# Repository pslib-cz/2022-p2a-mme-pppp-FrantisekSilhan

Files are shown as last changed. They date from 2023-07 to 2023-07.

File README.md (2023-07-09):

# Sorting "pointer"

 

For creating random teams, assigning people to teams, assigning people to work groups or training activities.

# What is needed?
- [strip board](https://www.aliexpress.com/item/1005001298180557.html) 25x9 holes (35 CZK / 5pcs)
- [Arduino Nano](https://www.aliexpress.com/item/1005005655120765.html) (129 CZK)
- 9V battery (~40 CZK)
- 9V baterry [clip](https://www.aliexpress.com/item/32728912830.html) (11 CZK / 10pcs)
- [mini slide switch](https://www.allelectronics.com/item/ssw-86/spdt-mini-slide-switch/1.html) (10.0 x 5.5mm body) (22 CZK)
- 2 LED strips (5 LED + 1 LED) [WS2812B](https://www.aliexpress.com/item/1005002630710155.html) (140 CZK / 1m)
- 3 TTP223 [touch buttons](https://www.aliexpress.com/item/1005004970116737.html) (15 CZK / 10pcs)
- 3pin cable + [header connectors](https://www.aliexpress.com/item/32724478308.html) (~54 female + ~33 male) (70 CZK / 20pcs)
- Final price ~451 CZK (~20,79 USD 18.06.2023)

# How to create one

## Step 0:

Print [box](./stl/box.STL) and [lid](./stl/lid.STL) on a 3D printer

## Step 1: Solder the female connectors to the strip board

As shown in the picture below, solder the female connectors to the strip board. Solder the pins marked with a colored dot to the strip board, and remove the other pins from the connector.\
Leave exactly 5 holes between the connectors in the blue rectangle, as this is where the Arduino Nano will be inserted.

<p style="display: flex; align-items: flex-start; gap: 1em;">
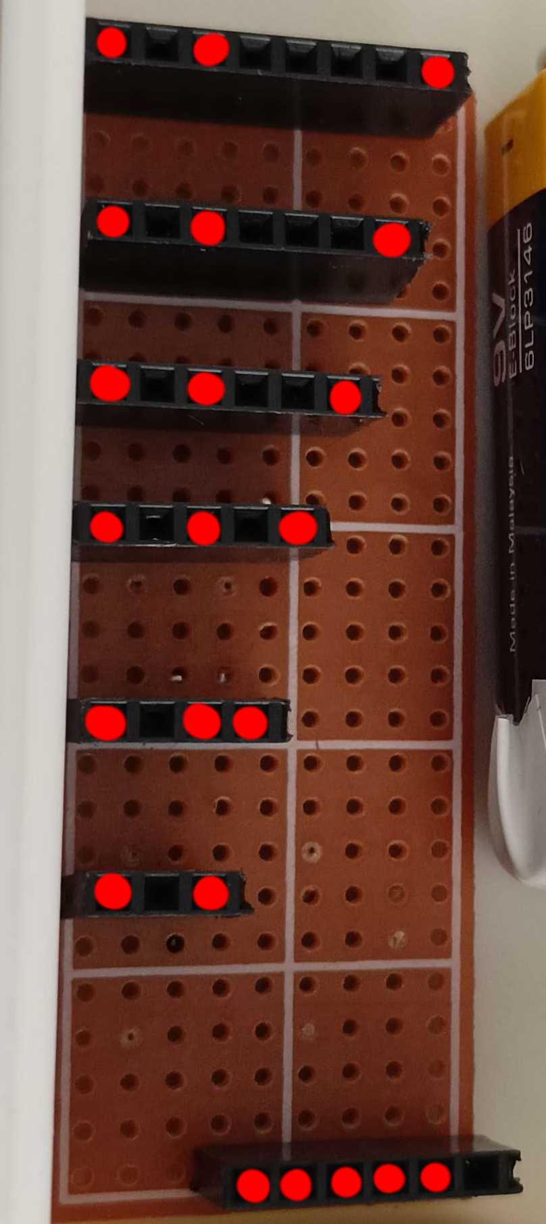
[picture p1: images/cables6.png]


</p>

## Step 2: Create male connectors for the cables

Solder a total of five male connectors to the cables, three of which are for the buttons and two for the LED strips.
Each cable will have the following pinout (based on the picture below):

- Ground pin will be on the far left.
- The two pins to the right of the ground pin will be the +5V pin.
- The data pin for each cable will be in a different location.

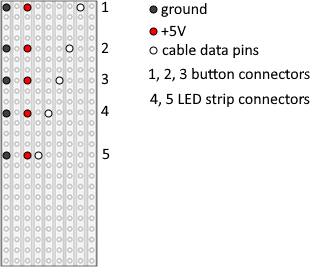
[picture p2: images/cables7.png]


For the three button cables, select the three longest connectors (labeled 1, 2 and 3 in the image above).\
For the two cables for the LED strips, select the two shortest connectors (marked 4 and 5).\
one LED strip will have 5 LEDs (marked with the number 5), the other LED strip will have only 1 LED (marked with the number 4).

## Step 2.5: Soldering the female connectors to the button cables and soldering the LED strips

Solder the female connectors to the other side of the button cables according to the pins on the buttons.

For LED strip cables, do not use female connectors, but solder the cables directly to the LED strip.

<p style="display: flex; align-items: flex-start; gap: 1em;">
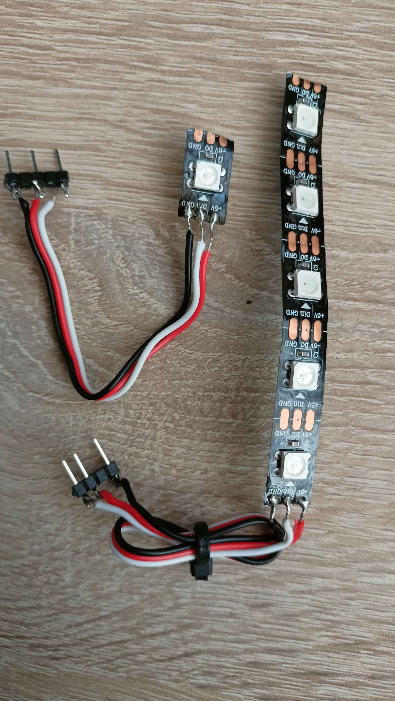
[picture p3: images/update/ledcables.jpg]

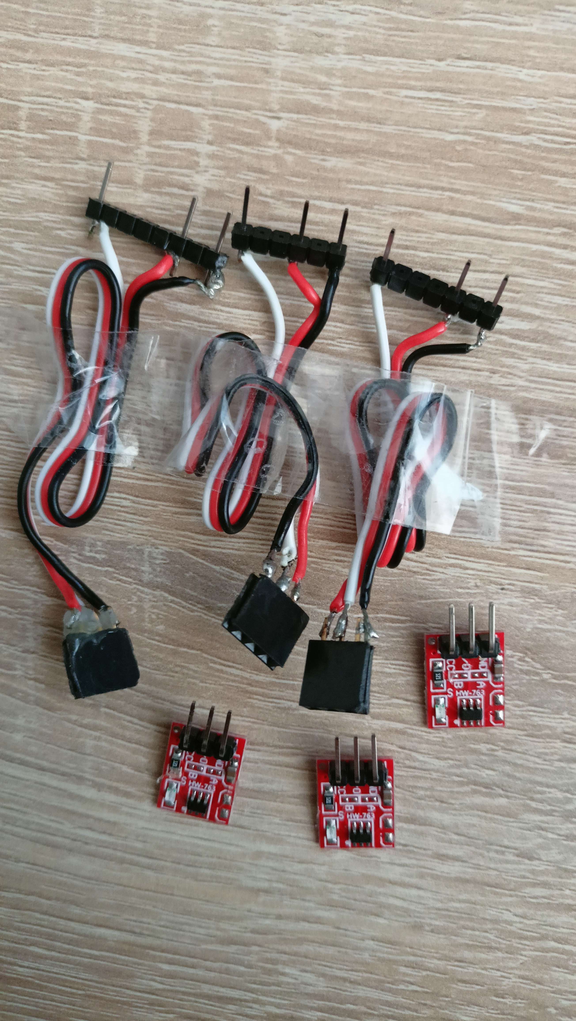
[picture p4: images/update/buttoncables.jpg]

</p>

Now you should have:
- 2 LED strip cables (one LED strip with 5 LEDs, the other LED strip with 1 LED)
- 3 cables for the buttons

## Step 3: Inserting into the box

Solder the ground from the 9V battery clip to the Arduino ground and connect the "+" of the 9V battery to the slide switch and then from the switch to the Uin of the Arduino.

Upload the provided [code](./main/main.ino) using the Arduino IDE to the Arduino and set the pins as required (according to the data pins in the image below).\
(Don't forget to include the FastLED library: Tools > Manage Libraries... (Ctrl + Shift + I) > search "FastLED" > INSTALL)

Next, insert the strip board into the box, plug the Arduino into the prepared connectors and place the battery next to it. Glue the switch into the prepared hole on the side of the box. (see image below)

Test if the Arduino turns on after you flip the switch.

<p style="display: flex; align-items: flex-start; gap: 1em;">
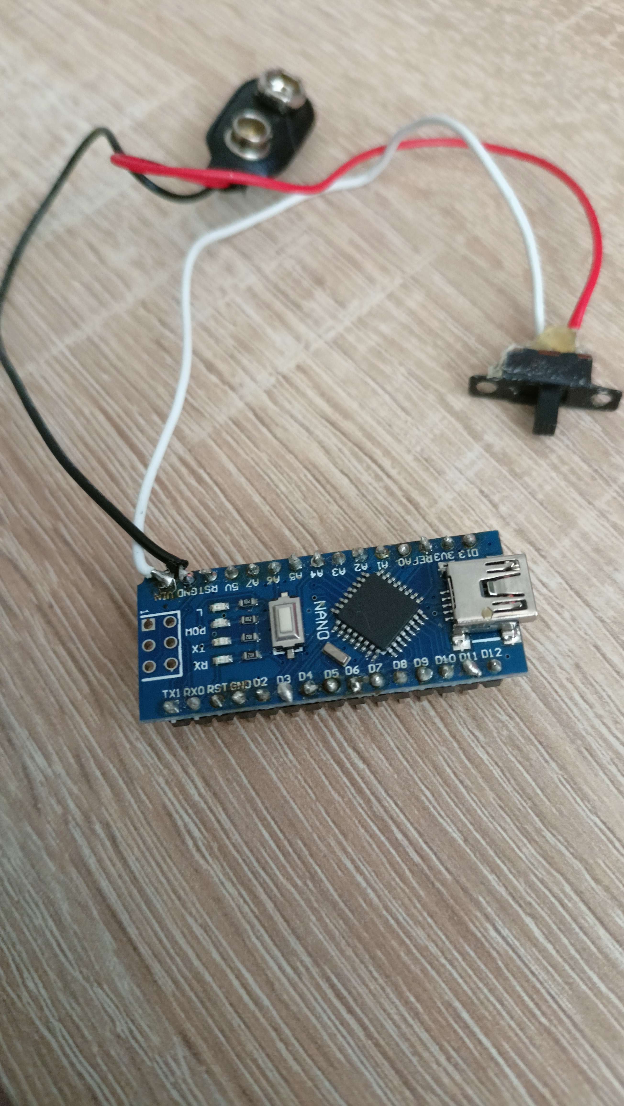
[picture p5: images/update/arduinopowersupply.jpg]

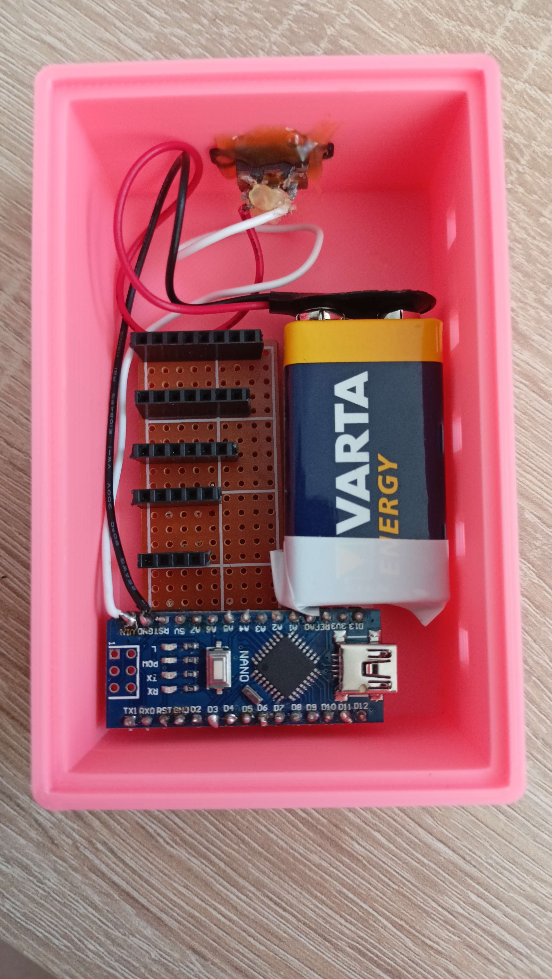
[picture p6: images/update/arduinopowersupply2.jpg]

</p>
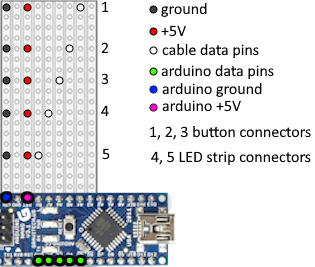
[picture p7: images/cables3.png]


## Step 4: Glue the buttons and LED strips into the lid and box

Glue all buttons and both LED strips into the prepared holes in the lid and box (see image below).

<p style="display: flex; align-items: flex-start; gap: 1em;">
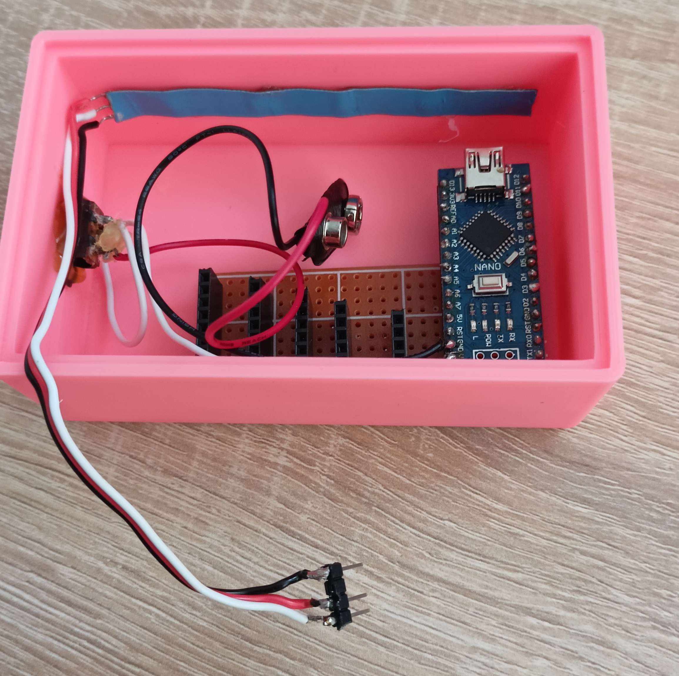
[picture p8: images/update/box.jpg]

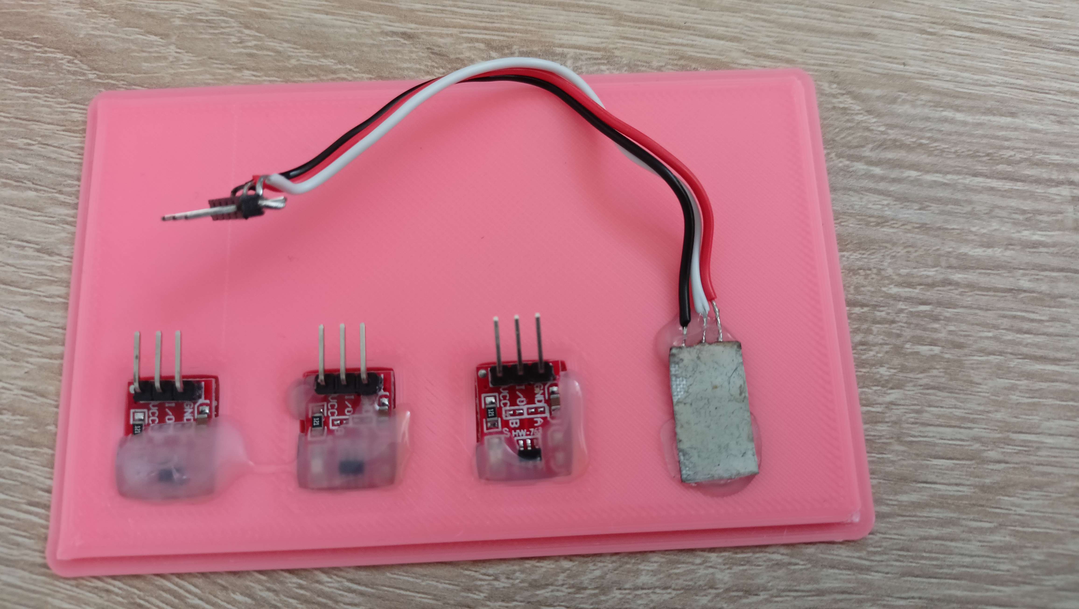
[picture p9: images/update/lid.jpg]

</p>

## Step 5: Connect all cables

Connect the prepared cables to the buttons with male connectors.\
Plug all cables into the female connectors on the strip board and close the box carefully.

Test that all buttons are working and all LEDs are showing output.

<p style="display: flex; align-items: flex-start; gap: 1em;">
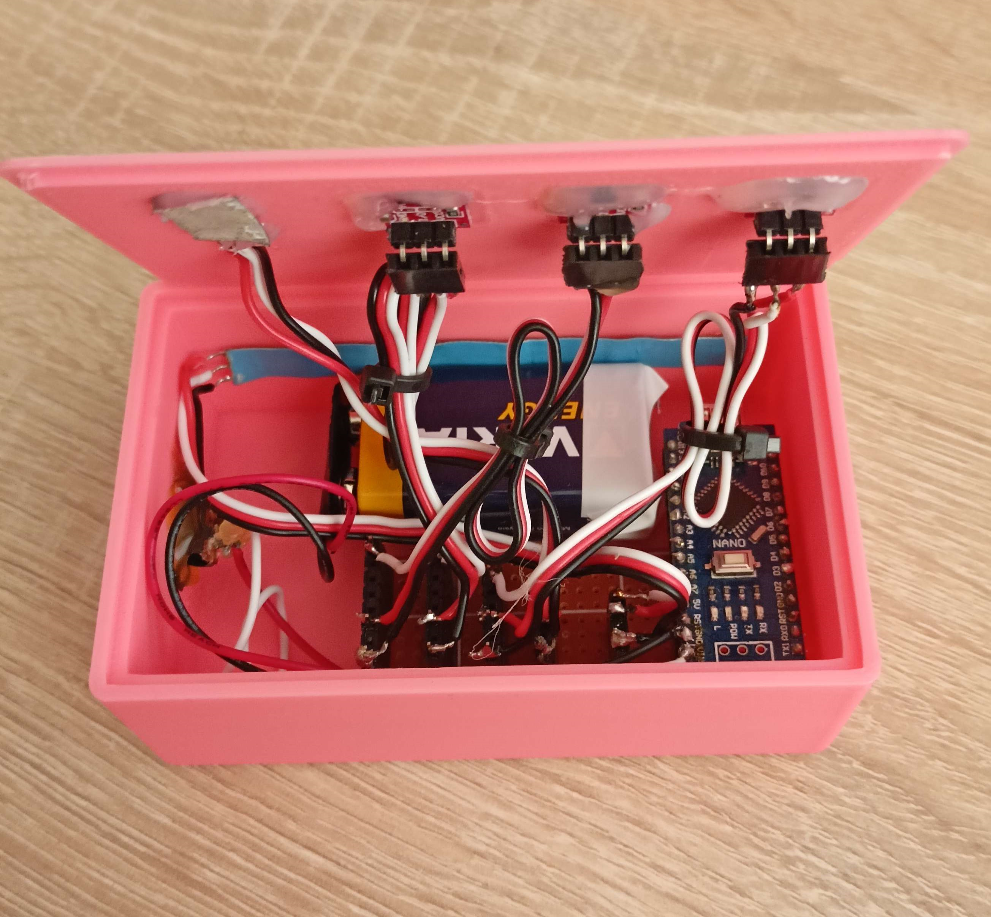
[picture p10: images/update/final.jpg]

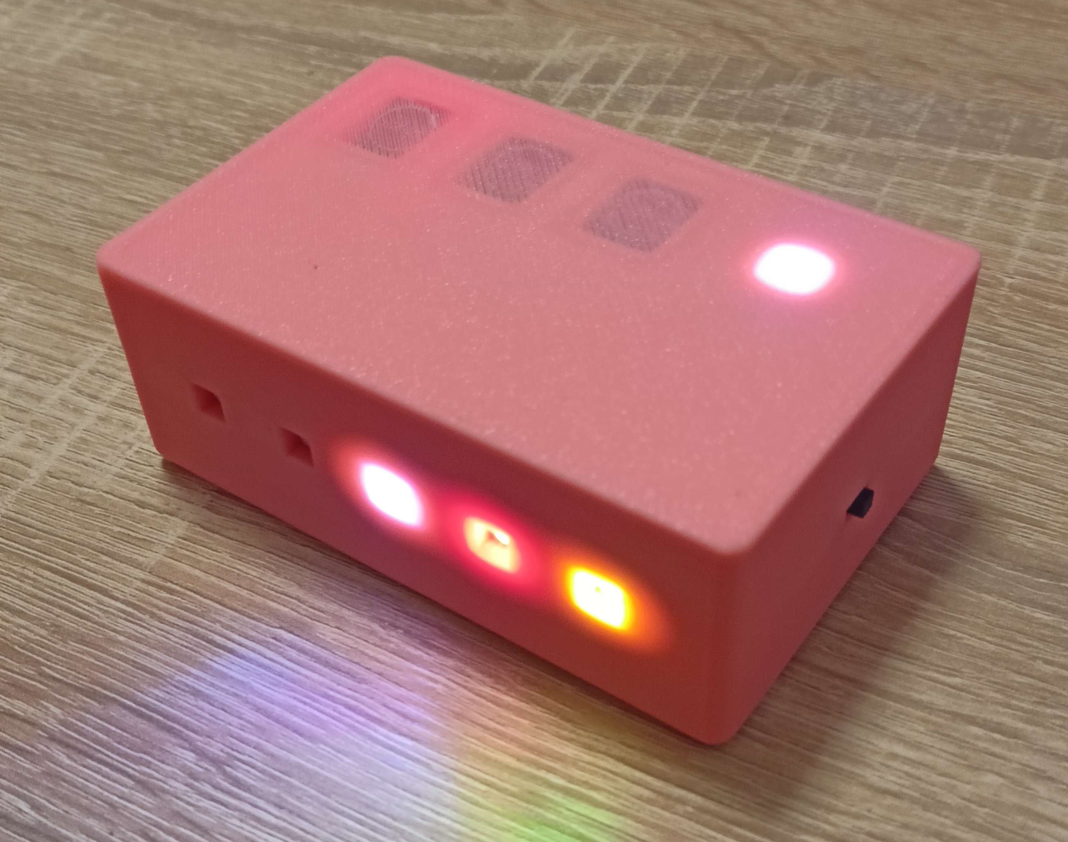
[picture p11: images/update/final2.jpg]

</p>

# Usage Instructions

The box has this basic layout (pins can be modified as needed in [code](./main/main.ino))

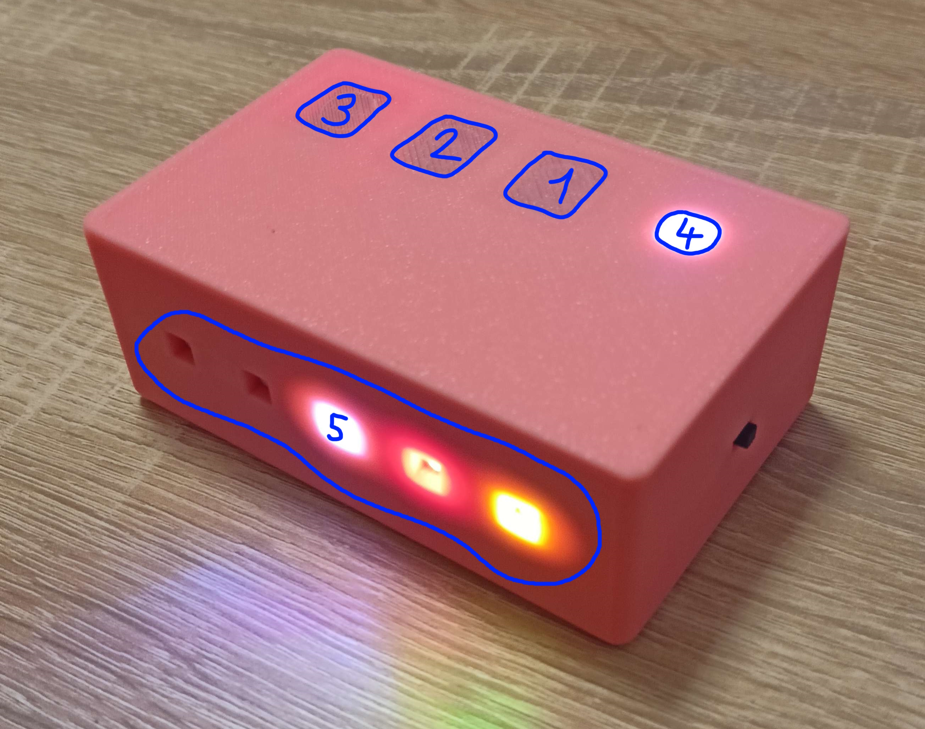
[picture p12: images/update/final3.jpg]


- 1 - Button to change the number of groups
    - When pressed, the number of selected groups will be shown on the top row of the LEDs (shown as a number 5 in the image)
    - The selection of the number of groups cycles from one group to the maximum number of groups, and then again from one group
- 2 - Button to change mode
    - Each press of the button changes the currently selected mode
    - The selected mode cycles between 3 modes (see point 4)
- 3 - Button for stepping
    - The main button that triggers one "draw" according to the selected mode
- 4 - LED showing the currently selected mode
    - The pointer has 3 modes
        - ## Green - Yes/No
            - Lights the LED strip green (YES) or red (NO)
            - Chance of YES is 50% and for each NO the chance of YES increases by 10%
            - If YES is displayed, the chance is set back to 50%
        - ## Red - Shift cycling group
            - Groups are progressively displayed by cycling the LED to the side
            - The LEDs on the output are each a different color, each color represents a different group
            - 
        - ## Blue - Random group cycling
            - Works the same as the red mode, but the LED cycling is not to the side, but a random group is always selected. The final number of people in a group is even
            - 
- 5 - LEDs showing an output
    - Each time the step button is pressed, the output here is displayed according to the selected mode and number of groups
    - Each time the button to change the number of groups is pressed, the currently selected number of groups is displayed here

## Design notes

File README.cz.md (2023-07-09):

# Rozřazovací "ukazovátko"

 

Pro tvorbu náhodných týmů, rozřazení lidí do týmů, rozřazování do pracovních skupin nebo vzdělávacích aktivit.

# Co je potřeba?
- [strip board](https://www.aliexpress.com/item/1005001298180557.html) 25x9 děr (35 CZK / 10ks)
- [Arduino Nano](https://www.aliexpress.com/item/1005005655120765.html) (129 CZK)
- 9V baterie (~40 CZK)
- [Klip](https://www.aliexpress.com/item/32728912830.html) na 9V baterii (11 CZK / 10ks)
- [mini posuvný přepínač](https://www.allelectronics.com/item/ssw-86/spdt-mini-slide-switch/1.html) (10.0 x 5.5mm tělo) (22 CZK)
- 2 LED pásky (5 LED + 1 LED) [WS2812B](https://www.aliexpress.com/item/1005002630710155.html) (140 CZK / 1m)
- 3 TTP223 [dotyková tlačítka](https://www.aliexpress.com/item/1005004970116737.html) (15 CZK / 10ks)
- 3pinový kabel + [header konektory](https://www.aliexpress.com/item/32724478308.html) (~54 samičích + ~33 samčích) (70 CZK / 20ks)
- Finální cena ~451 CZK (18.06.2023)

# Výroba

## Krok 0:

Vytiskněte [krabičku](./stl/box.STL) a [víko](./stl/lid.STL) na 3D tiskárně

## Krok 1: Připájení samičích (female) konektorů na strip board

Podle obrázku níže připájejte samičí konektory na strip board. Piny označené barevnou tečkou připájejte ke strip boardu, zatímco ostatní piny vyjměte z konektoru.\
Mezeru mezi konektory v modrém obdélníku zanechte přesně 5 děr, protože zde bude zasazeno Arduino Nano.

<p style="display: flex; align-items: flex-start; gap: 1em;">


</p>

## Krok 2: Vytvoření samčích (male) konektorů pro kabely

Připájejte celkem pět samčích konektorů na kabely, z toho tři kabely pro tlačítka a dva kabely pro LED pásy.
Každý kabel bude mít následující uspořádání pinů (založené na obrázku níže):

- Ground pin bude úplně vlevo.
- Dva piny vpravo od ground pinu bude +5V pin.
- Data pin pro každý kabel bude na jiném místě.



Pro tři kabely pro tlačítka vyberte tři nejdelší konektory (označené jako 1, 2 a 3 v obrázku výše).\
Pro dva kabely pro LED pásy vyberte dva nejkratší konektory (označené jako 4 a 5).\
jeden LED pás bude mít 5 LEDek (označen číslem 5), druhý LED pás bude mít pouze 1 LEDku (označen číslem 4).

## Krok 2.5: Připájení samičích konektorů na tlačítkové kabely a připojení LED pásků

Připájejte samičí konektory na druhou stranu tlačítkových kabelů podle pinů na tlačítkách.

Pokud jde o kabely pro LED pásky, nepoužívejte samičí konektory, ale připájejte kabely přímo k LED pásku.

<p style="display: flex; align-items: flex-start; gap: 1em;">


</p>

Teď byste měli mít:
- 2 kabely s LED pásy (jeden LED pás s 5 LEDkami, druhý LED pás s 1 LEDkou)
- 3 kabely pro tlačítka

## Krok 3: Zasazení do boxu

Připájejte zem z klipu pro 9V baterii na zem Arduina a "+" 9V baterie přípájejte na posuvný přepínač a následně z přepínače na Uin Arduina.

Nahrajte připravený [kód](./main/main.ino) pomocí Arduino IDE do Arduina a nastavte piny dle potřeby (podle data pinů na obrázku níže).\
(Nezapomeňte připojit knihovnu FastLED: Tools > Manage Libraries... (Ctrl + Shift + I) > vyhledejte "FastLED" > INSTALL)

Následně vložte strip board do boxu, zasuňte Arduino do připravených konektorů a vedle položte baterii. Přepínač přilepte do připravené díry na boku krabičky. (viz foto níže)

Otestujte, zda se Arduino zapne po přepnutí přepínače.

<p style="display: flex; align-items: flex-start; gap: 1em;">


</p>


## Krok 4: Vlepení tlačítek a LED pásků do víka a boxu

Vlepte všechna tlačítka a oba LED pásky do připravených děr ve víku a krabičce. (viz foto níže)

<p style="display: flex; align-items: flex-start; gap: 1em;">


</p>

## Krok 5: Zapojení všech kabelů

Ke tlačítkům se samčími konektory zapojte připravené kabely.\
Zapojte všechny kabely do samičích konektorů na strip boardu a krabičku opatrně zavřete.

Otestujte, zda všechna tlačítka fungují a všechny LEDky zobrazují výstup.

<p style="display: flex; align-items: flex-start; gap: 1em;">


</p>

# Návod k použití

Krabička má toto základní rozložení (piny můžou být upraveny podle potřeby v [kódu](./main/main.ino))



- 1 - Tlačítko pro změnu počtu skupin
    - Po stisknutí se ukáže počet vybraných skupin na horní řadě LED (na obrázku zobrazeno číslem 5)
    - Výběr počtu skupin se točí od jedné skupiny do maximálního počtu skupin, a následně znovu od jedné skupiny
- 2 - Tlačítko pro změnu módu
    - Každým stisknutím tlačítka se změní aktuálně vybraný mód
    - Vybraný mód se točí mezi 3 módy (viz bod 4)
- 3 - Tlačítko pro krokování
    - Hlavní tlačítko, kterým se podle zvoleného módu spustí jedno "vylosování"
- 4 - LED zobrazující aktuálně vybraný mód
    - Ukazovátko má 3 módy
        - ## Zelená - Ano/Ne
            - Rozsvicuje LED pás zeleně (ANO) nebo červeně (NE)
            - Šance na ANO je 50% a při každém NE se šance na ANO zvýší o 10%
            - Pokud se zobrazí ANO, šance je nastavena zpět na 50%
        - ## Červená - Posuvné cyklení skupin
            - Postupně se ukazují skupiny cyklením LED do strany
            - LEDky na výstupu mají každá jinou barvu, každá barva reprezentuje jinou skupinu
            - 
        - ## Modrá - Náhodné cyklení skupin
            - Funguje stejně jako červený mód, ale cyklení LED není do strany, ale vybírá se vždy náhodná skupina tak, aby finální počet lidí ve skupině byl rovnoměrný
            - 
- 5 - LEDky zobrazující výstup
    - Po každém stisknutí krokovacího tlačítka se zde zobrazí výstup podle zvoleného módu a počtu skupin
    - Po každém stisknutí tlačítka pro změnu počtu skupin se zde zobrazí aktuálně vybraný počet skupin

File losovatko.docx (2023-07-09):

# losovací / rozřazovací "ukazovátko"

# Hardware požadavky

- LED diody pro zobrazení módu, počtu týmů a vybraných možností.
- Krabička navržená v SolidWorks pro ochranu a umístění všech komponent.

# Softwarové požadavky

- Implementace tří módů: Ano/Ne, Rozřazování do týmů a Náhodné rozřazování.
- Ovládání pomocí tlačítek.
- Zobrazování výstupů pomocí led diod.

# Funkční požadavky

- Možnost volby jednoho ze tří módů pomocí tlačítka.
- Zobrazení aktuálního módu na LED diodách.
- Možnost změny počtu týmů pomocí tlačítka (pro módy s výběrem počtu týmů).
- Spuštění / zastavení pomocí tlačítka.
- Zobrazování výstupu na LED diodách (vylosovaný tým nebo ano/ne).

# Nefunkční požadavky

- Spolehlivost – Zařízení by mělo být schopno pracovat bezchybně
- Přenosnost – Krabička by měla být lehká a snadno přenosná.
- Intuitivní ovládání – Uživatel by měl být schopen snadno ovládat zařízení bez potřeby složitého návodu.
- Bezpečnost – Krabička by měla chránit elektronické součástky

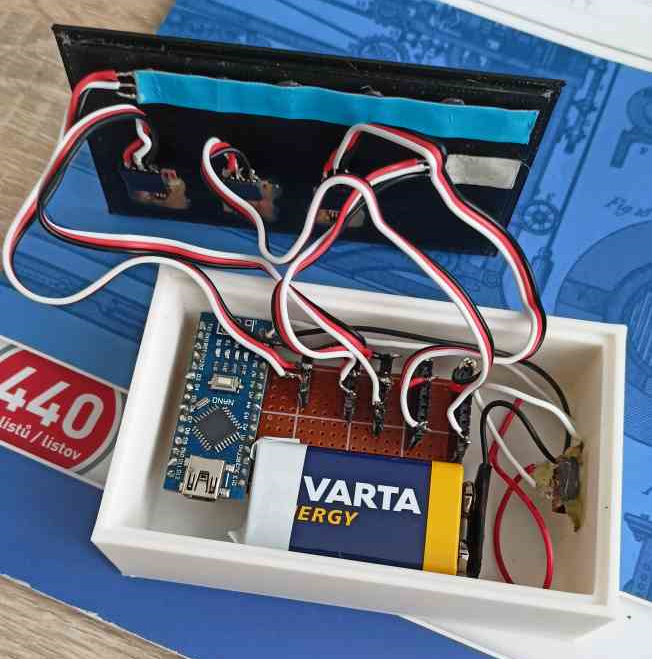
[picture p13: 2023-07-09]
images/box4.png

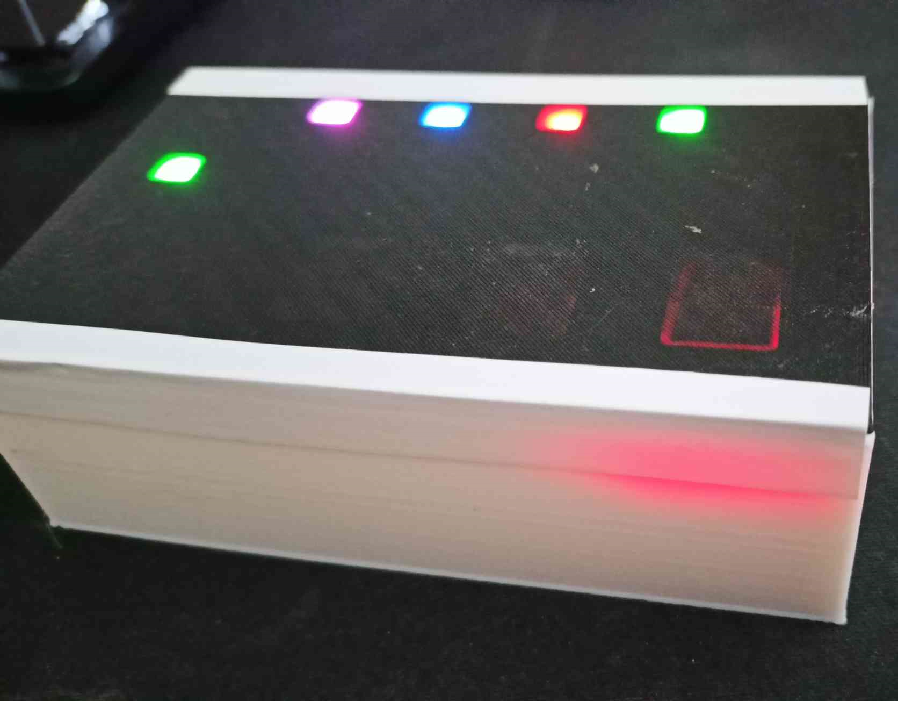
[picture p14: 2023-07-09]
images/box5.png

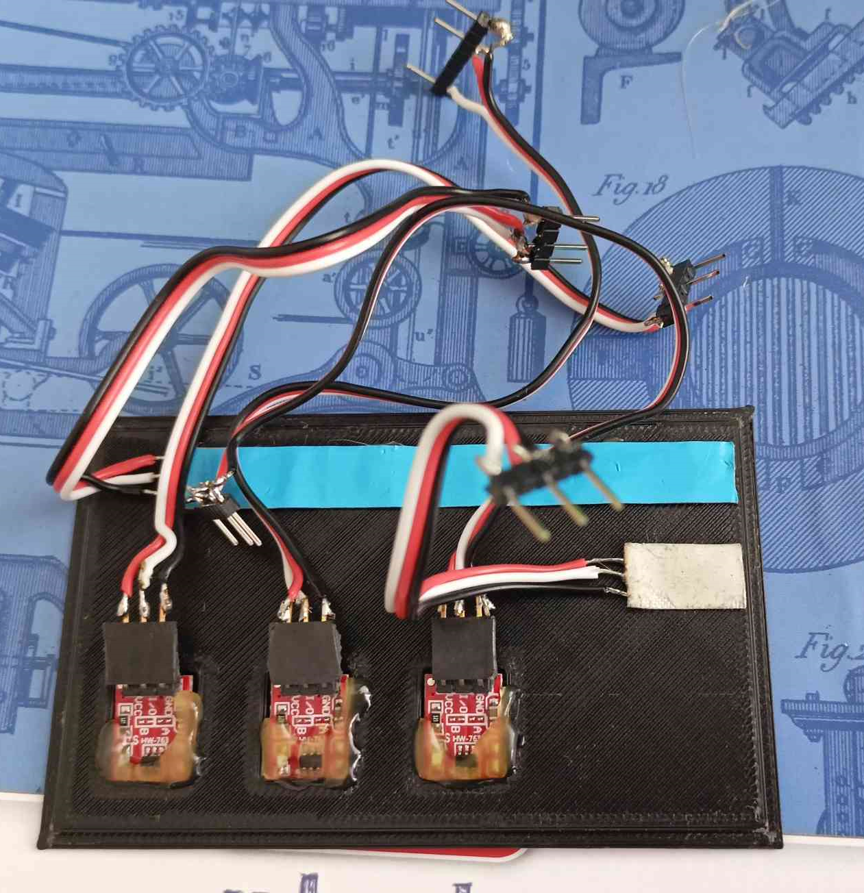
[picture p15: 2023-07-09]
images/box3.png

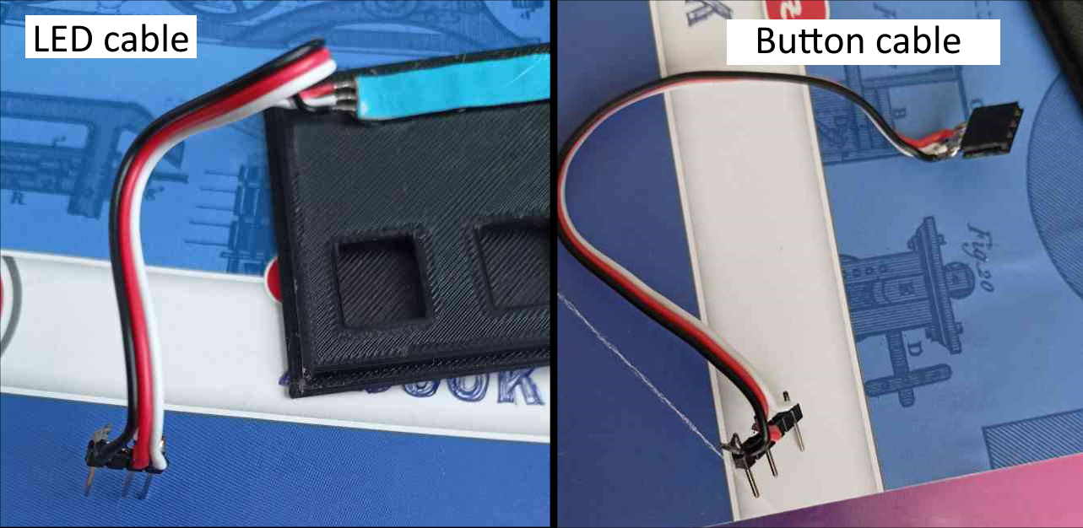
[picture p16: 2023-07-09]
images/cables4.png

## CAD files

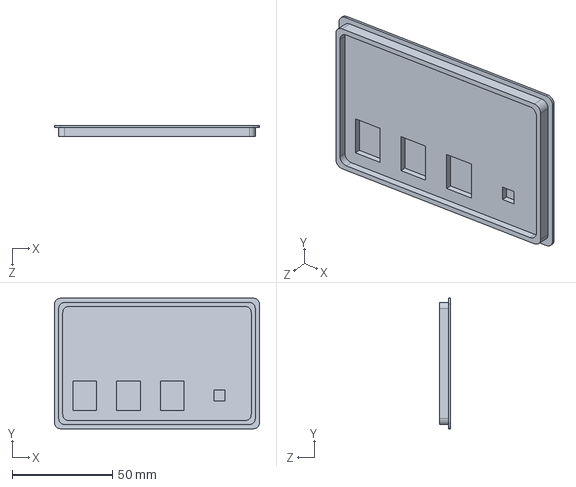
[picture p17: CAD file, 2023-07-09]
sldprt/lid.SLDPRT
102.0 x 65.0 x 5.60 mm

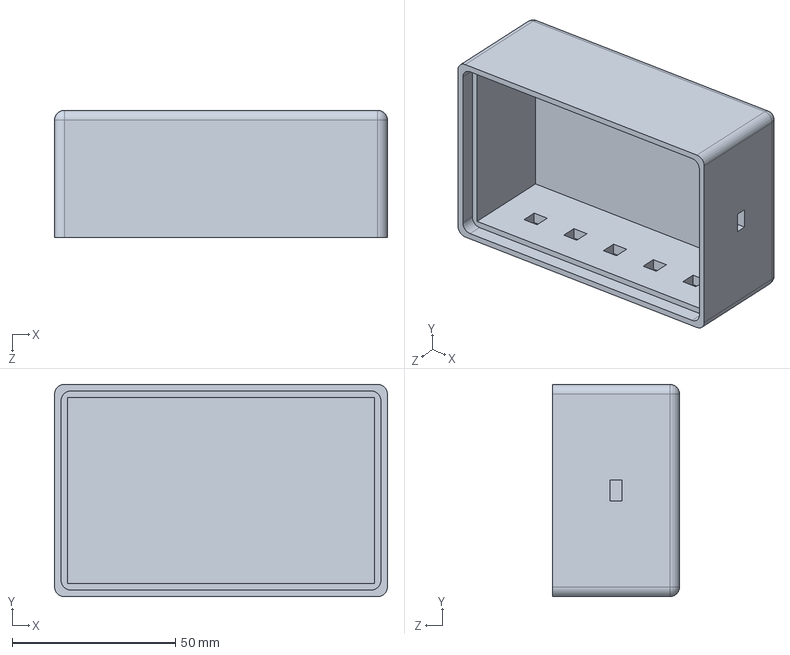
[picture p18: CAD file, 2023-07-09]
sldprt/box.SLDPRT
102.0 x 65.0 x 39.0 mm

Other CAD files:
stl/box.STL
stl/lid.STL

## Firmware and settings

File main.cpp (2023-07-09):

//nastavení pinů tlačítek a deklarace globálních proměnných
const int StepButtonPin = A5;
const int GroupButtonPin = 4;
const int ModeButtonPin = A4;

bool lastStepButton = false;
bool lastModeButton = false;
bool lastGroupButton = false;


int mode = 2;
int groups = 0;
int modeGroupGroup = 4;

int modeYesNoChance = 50;

int modeRandomGroupData[5];
int modeRandomGroupIndex = 0;

void resetLEDs() {
  // digitalWrite(A0, false);
  // digitalWrite(A1, false);
  // digitalWrite(A2, false);
  digitalWrite(7, false);
  digitalWrite(6, false);
  digitalWrite(3, false);
  digitalWrite(11, false);
  digitalWrite(9, false);
}

//točení/výběr módu
void advanceMode() {
  resetLEDs();
  mode = (mode + 1) % 3;

  analogWrite(A0, 0 == mode ? 130 : 0);
  analogWrite(A1, 1 == mode ? 130 : 0);
  analogWrite(A2, 2 == mode ? 150 : 0);
}
//točení/výběr skupin
void advanceGroup() {
  resetLEDs();
  groups += 1;
  if (groups == 5) {
    groups = 0;
  }
  digitalWrite(7, groups == 0);
  digitalWrite(6, groups == 1);
  digitalWrite(3, groups == 2);
  digitalWrite(11, groups == 3);
  digitalWrite(9, groups == 4);
}


//funkce s jednotlivými módy
bool modeYesNo() {
  const int number = random(0, 100);
  if (number < modeYesNoChance) {
    modeYesNoChance -= 10;
    return false;
  } else {
    modeYesNoChance = 50;
    return true;
  }
}

int modeRandomGroup() {
  for (int i = 0; i <= groups; i++) {
    int r = random(groups+1);
    bool found = false;
    
    for (int j = 0; j < modeRandomGroupIndex; j++) {
      if (modeRandomGroupData[j] == r) {
        found = true;
        break;
      }
    }
    if (!found) {
      modeRandomGroupData[modeRandomGroupIndex] = r;
      modeRandomGroupIndex++;
      if (modeRandomGroupIndex > groups) {
        modeRandomGroupIndex = 0;
        memset(modeRandomGroupData, 0, sizeof(modeRandomGroupData));
      }
      return r;
    }
  }
}

void switchLedFromNum(int num) {
  switch (num) {
    case 0:
      digitalWrite(7, true);
      break;
    case 1:
      digitalWrite(6, true);
      break;
    case 2:
      digitalWrite(3, true);
      break;
    case 3:
      digitalWrite(11, true);
      break;
    case 4:
      digitalWrite(9, true);
      break;
  }
}

//funkce při stisknutí hlavního krokového tlačítka
void step() {
  resetLEDs();
  switch(mode) {
    case 0:
      if (modeYesNo()) {
        digitalWrite(3, true);
      } else {
        digitalWrite(7, true);
      }
      break;
    case 1:
      modeGroupGroup = (modeGroupGroup + 1) % (groups + 1);
      switchLedFromNum(modeGroupGroup);
      break;
    case 2:
      switchLedFromNum(modeRandomGroup());
      break;
  }
}

void setup() {
  Serial.begin(9600);
  //nastavení ledek na zobrazení výstupu módů
  pinMode(7, OUTPUT);
  pinMode(6, OUTPUT);
  pinMode(3, OUTPUT);
  pinMode(11, OUTPUT);
  pinMode(9, OUTPUT);
  
  //nastavení ledek na zobrazení vybraného módu
  pinMode(A0, OUTPUT);
  pinMode(A1, OUTPUT);
  pinMode(A2, OUTPUT);

  //nastavení vstupu tlačítek
  pinMode(StepButtonPin, INPUT);
  pinMode(GroupButtonPin, INPUT);
  pinMode(ModeButtonPin, INPUT);

  //nastavení prvního módu při startu
  advanceMode();

  //nastavení seedu z nezapojeného analogového pinu
  randomSeed(analogRead(A3));
}

void loop() {
  const bool stepButton = digitalRead(StepButtonPin);
  const bool groupButton = digitalRead(GroupButtonPin);
  const bool modeButton = digitalRead(ModeButtonPin);

  if (lastStepButton != stepButton && stepButton) {
    step();
  }
  if (lastGroupButton != groupButton && groupButton) {
    advanceGroup();
    modeGroupGroup = -1;

    memset(modeRandomGroupData, 0, sizeof(modeRandomGroupData));
    modeRandomGroupIndex = 0;
  }
  if (lastModeButton != modeButton && modeButton) {
    advanceMode();
    modeGroupGroup = -1;

    memset(modeRandomGroupData, 0, sizeof(modeRandomGroupData));
    modeRandomGroupIndex = 0;
  }

  lastStepButton = stepButton;
  lastGroupButton = groupButton;
  lastModeButton = modeButton;

  delay(50);
}

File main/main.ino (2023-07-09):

#include <FastLED.h>

// pin definitions
#define MODE_LEDS_DATA_PIN 3
#define GROUP_LEDS_DATA_PIN 2
const int modeButtonPin = 6;
const int groupButtonPin = 5;
const int stepButtonPin = 4;

// global variables
#define MODE_LEDS 1
#define GROUP_LEDS 5
bool lastModeButton = false;
bool lastGroupButton = false;
bool lastStepButton = false;

const int modes = 3;
int mode = -1;

int group = -1;
int modeRandomGroupData[GROUP_LEDS];
int modeRandomGroupIndex = 0;
int modeRandomGroupCounter = 0;

CRGB colors[5] = {CRGB::Red, CRGB::Green, CRGB::Blue, CRGB::Cyan, CRGB::Yellow};

CRGB mode_leds[MODE_LEDS];
CRGB group_leds[GROUP_LEDS];

int modeYesNoChance = 50;
int modeGroupGroup = -1;
bool yes;

// function declarations
void shuffleArray(int* array, int size);
int modAdvance(int number, int mod);
void advanceMode();
void advanceGroup();
bool modeYesNo();
void modeGroup(int number);
int modeRandomGroup();
void clearLeds();
void step();

void setup() { 
  FastLED.addLeds<WS2812B, MODE_LEDS_DATA_PIN, RGB>(mode_leds, MODE_LEDS);
  FastLED.addLeds<WS2812B, GROUP_LEDS_DATA_PIN, RGB>(group_leds, GROUP_LEDS);
  FastLED.setBrightness(50);

  randomSeed(analogRead(A0));

  advanceMode();
  advanceGroup();
  for (int i = 0; i < GROUP_LEDS; i++) {
    modeRandomGroupData[i] = i;
  }
  shuffleArray(modeRandomGroupData, GROUP_LEDS);
}

int modAdvance(int number, int mod) {
  return (number + 1) % mod;
}

void advanceMode() {
  mode = modAdvance(mode, modes);
  mode_leds[0] = colors[mode];
}

void advanceGroup() {
  group = modAdvance(group, GROUP_LEDS);
  for (int i = 0; i < GROUP_LEDS; i++) {
    group_leds[i] = i <= group ? colors[i] : CRGB::Black;
  }
}

bool modeYesNo() {
  const int number = random(0, 100);
  if (number < modeYesNoChance) {
    modeYesNoChance -= 10;
    return false;
  } else {
    modeYesNoChance = 50;
    return true;
  }
}

void modeGroup(int number) {
  if (number == -2) {
    modeGroupGroup = modAdvance(modeGroupGroup, group + 1);
    number = modeGroupGroup;
  }
  for (int i = 0; i < GROUP_LEDS; i++) {
    group_leds[i] = i == number ? colors[i] : CRGB::Black;
  }
}

void shuffleArray(int* array, int size) {
  if (group == 1) return;
  for (int i = size - 1; i > 0; i--) {
    int j = random(i + 1);
    int temp = array[i];
    array[i] = array[j];
    array[j] = temp;
  }
}

int modeRandomGroup() {
  if (group == 0) {
    return 0;
  }
  if (modeRandomGroupCounter > group) {
    shuffleArray(modeRandomGroupData, GROUP_LEDS);
    modeRandomGroupCounter = 0;
    modeRandomGroupIndex = -1;
  }
  do {
    modeRandomGroupIndex = modAdvance(modeRandomGroupIndex, GROUP_LEDS);
  } while (modeRandomGroupData[modeRandomGroupIndex] > group);

  modeRandomGroupCounter++;
  return modeRandomGroupData[modeRandomGroupIndex];
}

void clearLeds() {
  FastLED.clear();
  FastLED.show();
  mode_leds[0] = colors[mode];
}

void step() {
  clearLeds();
  switch(mode) {
    case 0:
      yes = modeYesNo();
      for (int i = 0; i < GROUP_LEDS; i++) {
          group_leds[i] = yes ? colors[0] : colors[1];
      }
      break;
    case 1:
      modeGroup(-2);
      break;
    case 2:
      modeGroup(modeRandomGroup());
      break;
  }
}

void loop() {
  const bool modeButton = digitalRead(modeButtonPin);
  if (modeButton != lastModeButton && modeButton) {
    advanceMode();

    modeGroupGroup = -1;
    modeRandomGroupCounter = GROUP_LEDS;
    modeYesNoChance = 50;
  }
  lastModeButton = modeButton;

  const bool groupButton = digitalRead(groupButtonPin);
  if (groupButton != lastGroupButton && groupButton) {
    advanceGroup();

    modeGroupGroup = -1;
    modeRandomGroupCounter = GROUP_LEDS;
    modeYesNoChance = 50;
  }
  lastGroupButton = groupButton;

  const bool stepButton = digitalRead(stepButtonPin);
  if (stepButton != lastStepButton && stepButton) {
    step();
  }
  lastStepButton = stepButton;

  delay(50);
  FastLED.show();
}

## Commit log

2023-07-09 kod na arduino nano
2023-07-09 roztrizeni do souboru
    [krabicka.stl, viko.stl]
2023-07-09 přidání sldprt a přejmenování souboru
    [krabicka.SLDPRT, viko.SLDPRT]
2023-07-09 ta krabička je odpad, ale ostatní se zdá býti done
    [box.SLDPRT, box.STL, krabicka.SLDPRT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]
2023-07-09 update krabičky
    [box.SLDPRT, box.STL, viko.SLDPRT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]
2023-07-09 uprava vika
    [viko.SLDPRT, viko.stl]
2023-07-09 update víčka
    [box.SLDPRT, box.STL, viko.SLDPRT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]
2023-07-09 add small pause between leds
2023-07-09 edit model
    [box.SLDPRT, box.STL, viko.SLDPRT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]
2023-07-09 edit readme images, edit box
    [box.SLDPRT, box.STL, viko.SLDPRT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]
2023-07-09 edit box
    [box.SLDPRT, box.STL]
2023-07-09 update odchylka
    [viko-bez-odchylky.STL, viko.SLDPRT, viko.stl]
2023-07-09 update name
    [lid.STL, viko.stl]
